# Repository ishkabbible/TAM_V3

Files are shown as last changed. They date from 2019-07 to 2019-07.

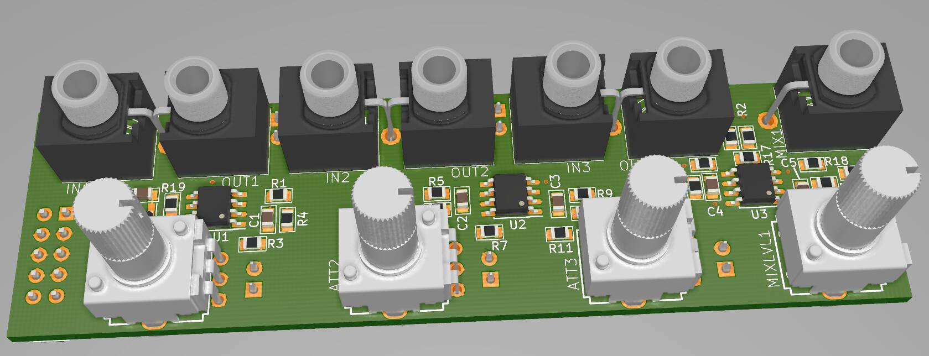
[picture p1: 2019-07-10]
active_3attMix_v3 PCB 3D front perspective.jpg

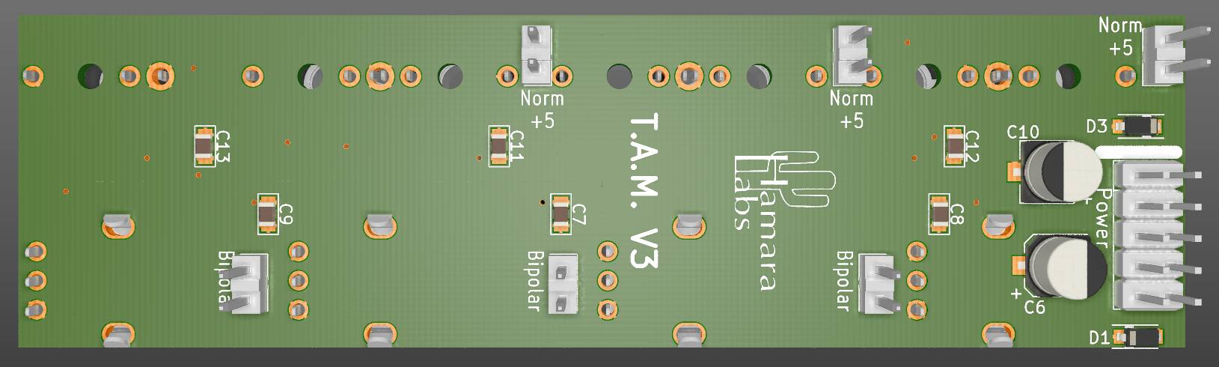
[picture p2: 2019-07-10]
active_3attMix_v3 PCB 3D back.jpg

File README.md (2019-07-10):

# Triple_Attenuverter_Mixer_v3

The TAM is three precision attenuators/attenuverters feeding into a 3-input, non-inverting mixer. The attenuXer sections are fully independent, and the output jacks are normalled to the mixer. Each section has 2 jumpers: one to select attenuator (gain = [0, +1]) or attenuverter (gain = [-1, +1]) operation. The other selects whether the input is normalled to +5V.

Additionally, this repository contains 2 different panel designs, the 3U x 6hp vertical panel, and a 1U x 20hp "tile" design. You will want to add knobs to the 1U build, since the pointer on the pots will be pointing sideways. The panel designs are identical to V2 and have not been updated.

LICENSE: The more I read about open source hardware licensing, the more confused I become. Apparently there is no real legal framework for it. That said, everyone seems to be doing it, so I'll join the crowd and hope the law eventually catches up with the people.
There is nothing unique or clever in this design, just the one op-amp attenuverter that everyone uses, and a non-inverting summer. I expect there are a dozen modules out there that have nearly the identical schematic. 
So I am releasing this design under the CC-BY-SA license. Feel free to contact me at ishkabbible at gmail.com if you feel I should be crediting you for any part of the design.

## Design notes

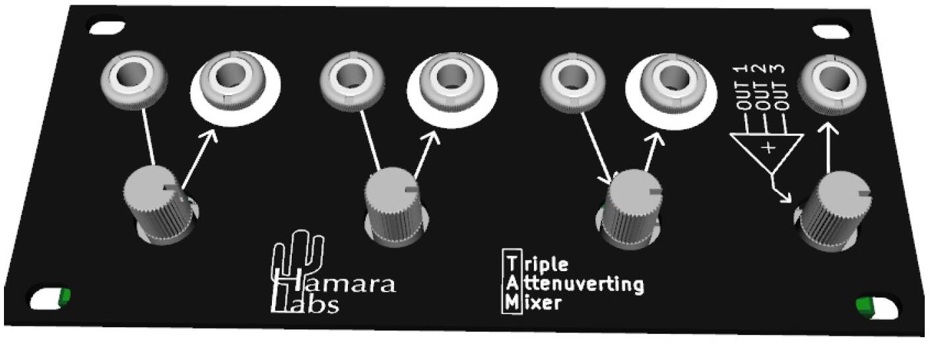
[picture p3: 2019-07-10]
active_3attMix V3 1u 3D.jpg

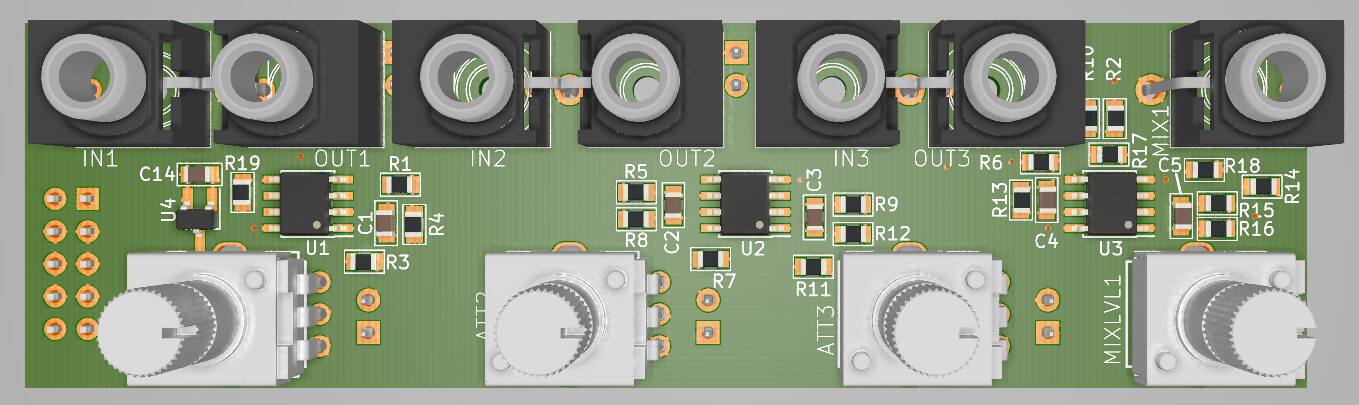
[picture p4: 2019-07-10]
active_3attMix_v3 PCB 3D front.jpg

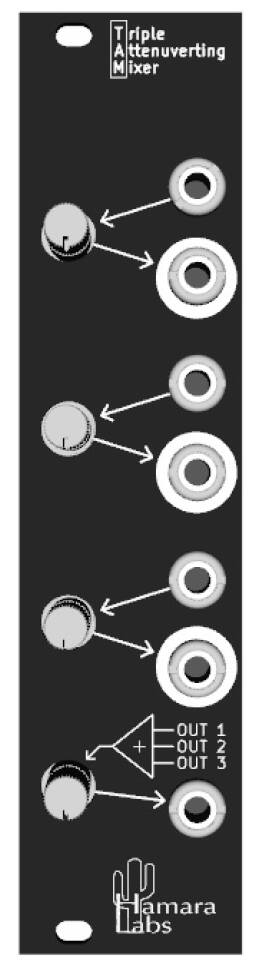
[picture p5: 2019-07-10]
active_3attMix_v3 3D front.jpg

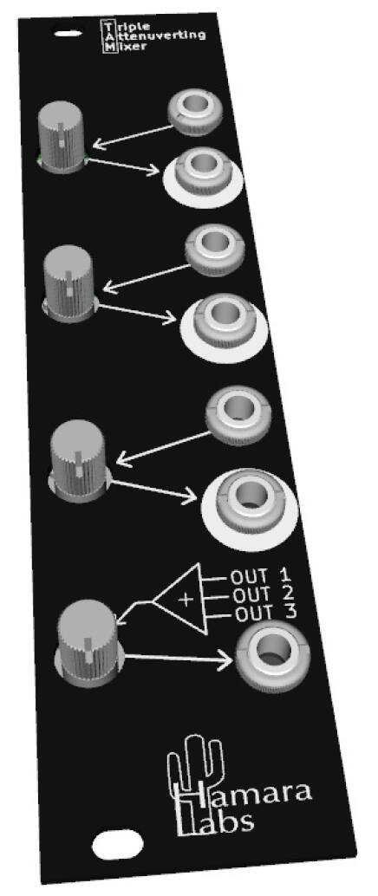
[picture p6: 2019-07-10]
active_3attMix_v3 3D front perspective.jpg

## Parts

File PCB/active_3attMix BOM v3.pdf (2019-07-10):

| | | | | NOTE: Prices are for rough planning only, they change on a daily basis
Quantity | Designator | Designation | Package | Vendor | | each | ext. | Notes
2 | C6,C10 | 22uF | CP_Elec_5x5.8 | Mouser | 667-EEE-FK1E220R (http://www.mouser.com/search/refine.aspx?Keyword=667-EEE-FK1E220R) | $0.41 | $0.82
1 | U4 | LM4040C50FTA | LM4040-5 | Mouser | 522-LM4040C50FTA (http://www.mouser.com/search/refine.aspx?Keyword=522-LM4040C50FTA) | $0.64 | $0.64 | Use LM4040A for more accurate 5V normaled to the inputs
3 | U1,U2,U3 | OPA1678IDR | SOIC-8_3.9x4.9mm_Pitch1.27mm | Mouser | 595-OPA1678IDR (https://www.mouser.com/Search/ProductDetail.aspx) | $0.83 | $2.49 | TL072 is cheaper if you don't care about performance
2 | D3,D1 | 1N5819HW-7-F | D_SOD-123 | Mouser | 621-1N5819HW-F (http://www.mouser.com/search/refine.aspx?Keyword=621-1N5819HW-F) | $0.44 | $0.88
1 | X1 | Header 2 x 5, 0.1" | HEADER_2.54_2x5 | | 538-10-89-7101 (http://www.mouser.com/ProductDetail/Molex/10-89-7101/) | $0.57 | $0.57 | Available cheaper elsewhere
6 | JP6,JP5,JP4,JP3,JP2,JP1 | header-2P, 0.1" | jump-2P | | 571-826936-2 (http://www.mouser.com/ProductDetail/TE-Connectivity/826936-2/) | $0.10 | $0.60 | Available cheaper elsewhere
7 | IN1,IN2,IN3,MIX1,OUT1,OUT2,OUT3 | PJ301M-12 / PJ398SM Jack | PJ301M-12_shared_ground | Thonk | https://www.thonk.co.uk/shop/3-5mm-jacks/ | $0.53 | $3.71 | must buy nuts separately. PJ398SM is upgraded part
3 | ATT1,ATT2,ATT3 | 100K | POT_SONG_HUEI_9mm_tall_trimmer | Thonk | https://www.thonk.co.uk/shop/ttpots/ | $1.11 | $3.33 | Linear for CV math, Audio for audio mixer
1 | MIXLVL1 | 10K | POT_SONG_HUEI_9mm_tall_trimmer | Thonk | https://www.thonk.co.uk/shop/ttpots/ | $1.11 | $1.11 | Linear for CV math, Audio for audio mixer
5 | C1,C2,C3,C4,C5 | 10pF | C_0805_DKH | Mouser | 77-VJ0805A100GXAPBC (https://www.mouser.com/Search/ProductDetail.aspx) | $0.10 | $0.50
7 | C7,C8,C9,C11,C12,C13,C14 | 100nF | C_0805_DKH | Mouser | 581-08055C104KAT4A (https://www.mouser.com/Search/ProductDetail.aspx) | $0.10 | $0.70
10 | R1,R2,R3,R5,R6,R7,R9,R10,R11,R15 | 200K, 0.1% | R_0805_DKH | Mouser | 603-AT0805BRD07200KL (https://www.mouser.com/Search/ProductDetail.aspx) | $0.26 | $2.61
4 | R4,R8,R12,R16 | 330R | R_0805_DKH | Mouser | 603-RC0805FR-07330RL (https://www.mouser.com/Search/ProductDetail.aspx) | $0.02 | $0.06 | buy 10
2 | R13,R14 | 120K, 0.1% | R_0805_DKH | Mouser | 603-RT0805BRD07120KL (https://www.mouser.com/Search/ProductDetail.aspx) | $0.39 | $0.78
1 | R17 | 43K | R_0805_DKH | Mouser | 603-RC0805FR-0743KL (https://www.mouser.com/Search/ProductDetail.aspx) | $0.10 | $0.10
1 | R18 | 75K | R_0805_DKH | Mouser | 603-RC0805FR-0775KL (https://www.mouser.com/Search/ProductDetail.aspx) | $0.10 | $0.10
1 | R19 | 10K | R_0805_DKH | Mouser | 603-RC0805FR-0710KL (https://www.mouser.com/Search/ProductDetail.aspx) | $0.10 | $0.10
6 | JP6,JP5,JP4,JP3,JP2,JP1 | | 2-pin Jumpers | Mouser | 806-SX1100-B (http://www.mouser.com/ProductDetail/Kycon/SX1100-B/) | $0.02 | $0.13 | buy 25, available cheaper elsewhere

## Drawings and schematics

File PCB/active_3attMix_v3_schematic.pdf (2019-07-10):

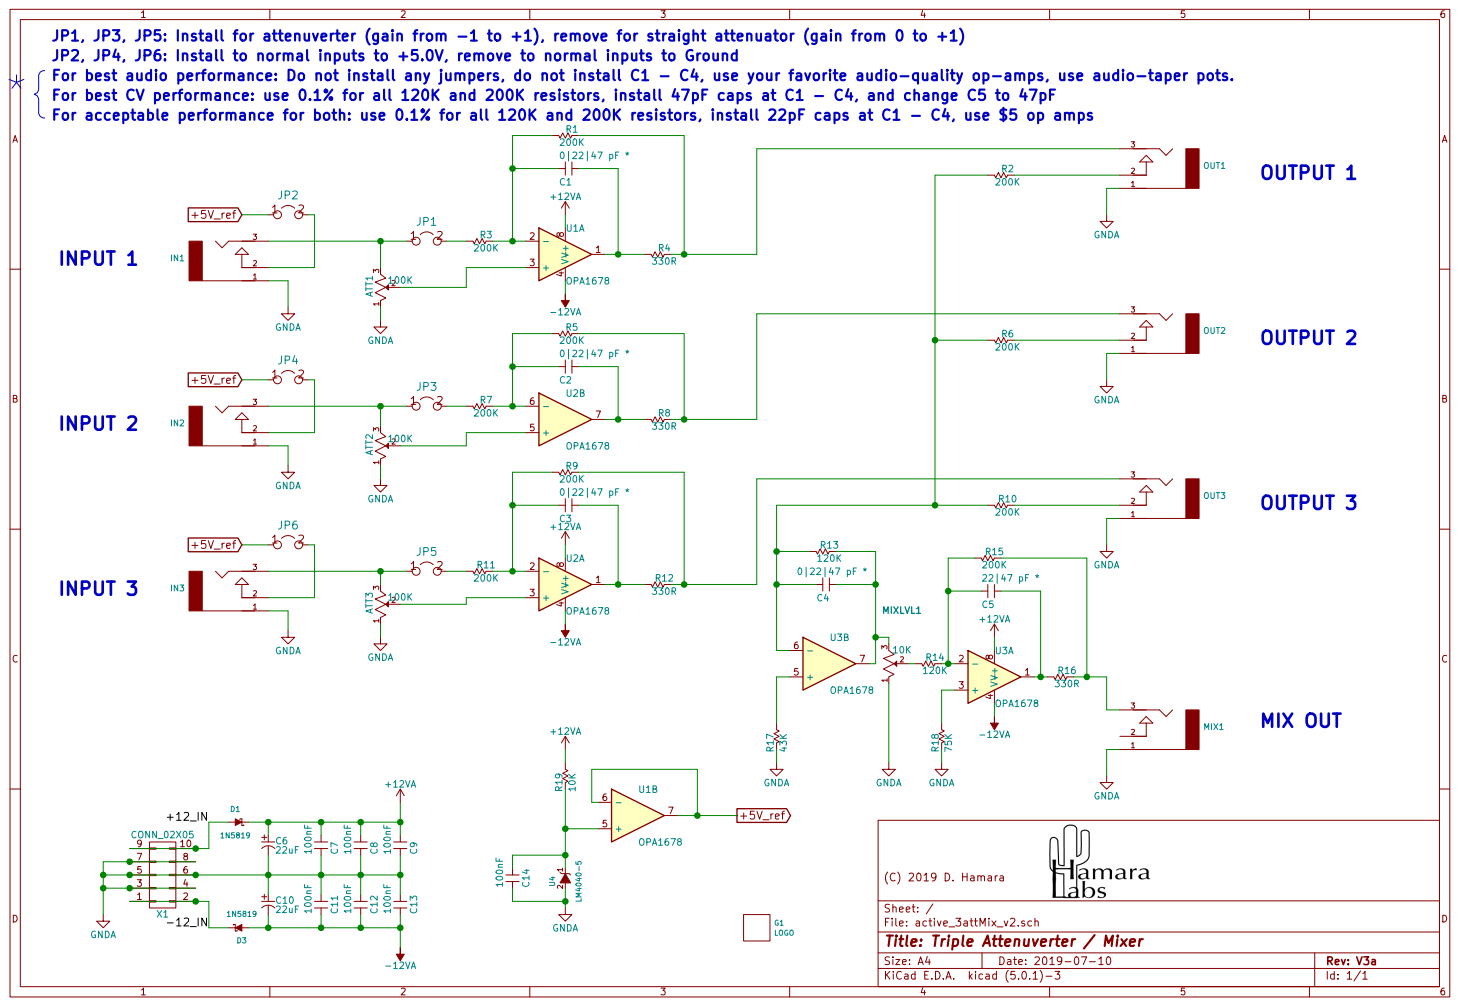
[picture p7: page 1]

JP1, JP3, JP5: Install for attenuverter (gain from -1 to +1), remove for straight attenuator (gain from 0 to +1)
JP2, JP4, JP6: Install to normal inputs to +5.0V, remove to normal inputs to Ground
For acceptable performance for both: use 0.1% for all 120K and 200K resistors, install 22pF caps at C1 - C4, use $5 op amps *{
120K For best audio performance: Do not install any jumpers, do not install C1 - C4, use your favorite audio-quality op-amps, use audio-taper pots.
For best CV performance: use 0.1% for all 120K and 200K resistors, install 47pF caps at C1 - C4, and change C5 to 47pF

File: active_3attMix_v2.sch Sheet: / (C) 2019 D. Hamara

Id: 1/1 Title: Triple Attenuverter / Mixer

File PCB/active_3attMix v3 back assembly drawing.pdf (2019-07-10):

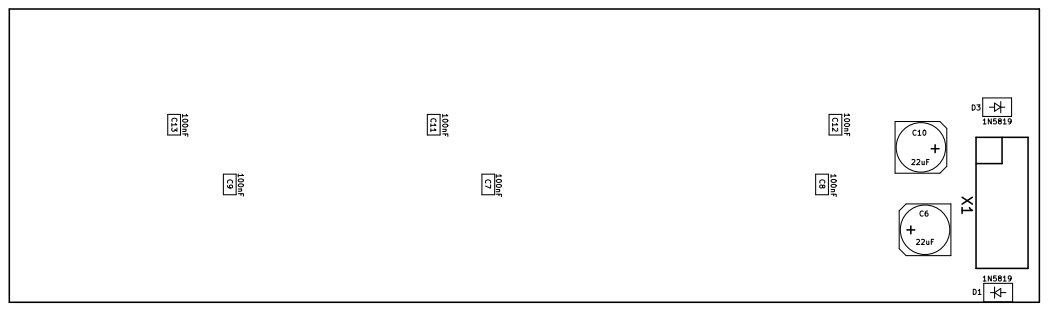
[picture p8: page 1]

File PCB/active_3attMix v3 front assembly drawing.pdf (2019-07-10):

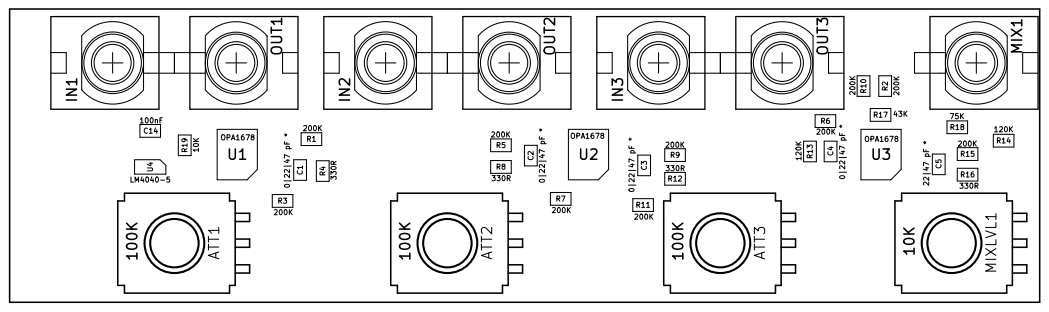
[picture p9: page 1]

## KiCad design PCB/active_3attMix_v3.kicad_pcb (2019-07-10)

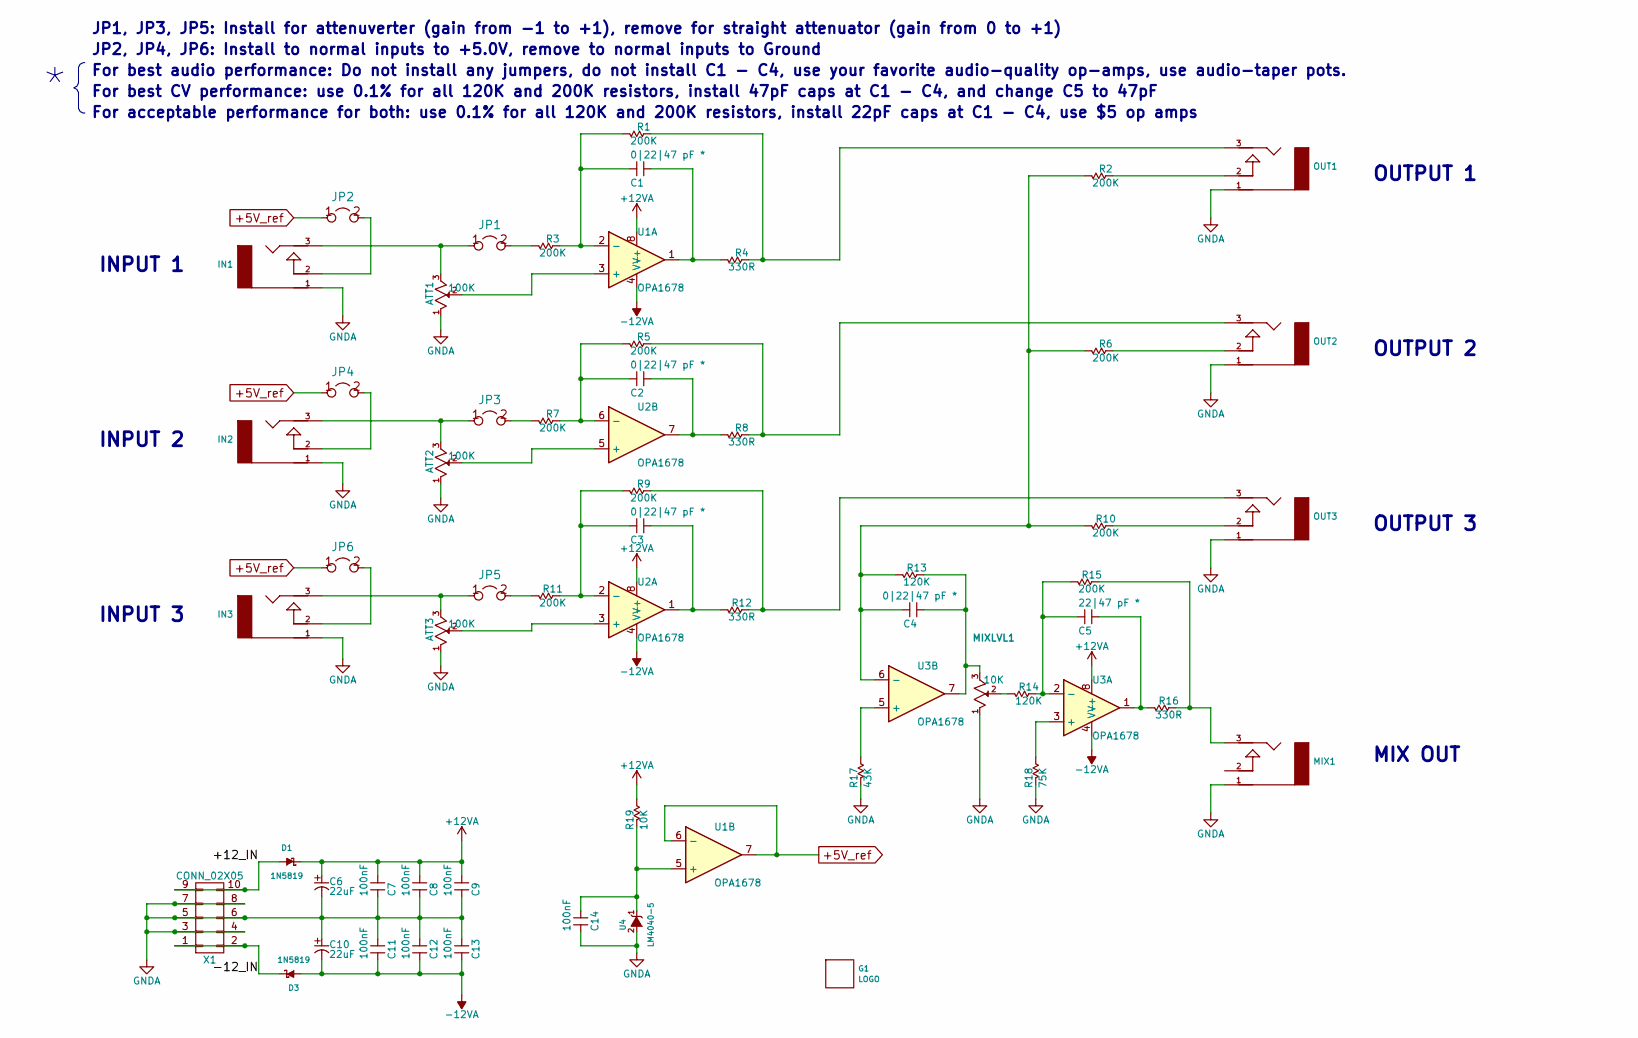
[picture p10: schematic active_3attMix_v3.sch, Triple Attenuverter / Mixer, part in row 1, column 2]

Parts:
ATT1, ATT2, ATT3: 100K; POT_SONG_HUEI_9mm_tall_trimmer
C1, C2, C3, C4: 0|22|47 pF *; C_0805_DKH
C5: 22|47 pF *; C_0805_DKH
C6, C10: 22uF; CP_Elec_5x5.8
C7, C8, C9, C11, C12, C13, C14: 100nF; C_0805_DKH
D1, D3: 1N5819; D_SOD-123
G1: LOGO; Hamara_labs_4_tiny
IN1, IN2, IN3: AUDIO-JACK-PJ301M-12; PJ301M-12_veils_sharedGround
JP1, JP2, JP3, JP4, JP5, JP6: header-2P; jump-2P
MIX1: AUDIO-JACK-PJ301M-12; PJ301M-12_veils_sharedGround
MIXLVL1: 10K; POT_SONG_HUEI_9mm_tall_trimmer
OUT1, OUT2, OUT3: AUDIO-JACK-PJ301M-12; PJ301M-12_veils_sharedGround
R1, R2, R3, R5, R6, R7, R9, R10, R11, R15: 200K; R_0805_DKH_hand
R4, R8, R12, R16: 330R; R_0805_DKH_hand
R13, R14: 120K; R_0805_DKH_hand
R17: 43K; R_0805_DKH_hand
R18: 75K; R_0805_DKH_hand
R19: 10K; R_0805_DKH_hand
U1, U2, U3: OPA1678; SOIC-8_3.9x4.9mm_Pitch1.27mm
U4: LM4040-5; SOT-23_Handsoldering
X1: CONN_02X05; HEADER_2.54_2x5

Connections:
+5V_ref: JP2.1, JP4.1, JP6.1, U1.6 (-), U1.7
+12VA: C6.1, C7.1, C8.1, C9.1, D1.1 (K), R19.2, U1.8 (V+), U2.8 (V+), U3.8 (V+)
-12VA: C10.2, C11.2, C12.2, C13.2, D3.2 (A), U1.4 (V-), U2.4 (V-), U3.4 (V-)
/+12_IN: D1.2 (A), X1.9, X1.10
/-12_IN: D3.1 (K), X1.1, X1.2
GNDA: ATT1.1, ATT2.1, ATT3.1, C6.2, C7.2, C8.2, C9.2, C10.1, C11.1, C12.1, C13.1, C14.2, IN1.1 (RING), IN2.1 (RING), IN3.1 (RING), MIX1.1 (RING), MIXLVL1.1, OUT1.1 (RING), OUT2.1 (RING), OUT3.1 (RING), R17.1, R18.1, U4.2 (A), X1.3, X1.4, X1.5, X1.6, X1.7, X1.8
unnamed: ATT1.2, U1.3 (+)
unnamed: ATT1.3, IN1.3 (TIP), JP1.1
unnamed: ATT2.2, U2.5 (+)
unnamed: ATT2.3, IN2.3 (TIP), JP3.1
unnamed: ATT3.2, U2.3 (+)
unnamed: ATT3.3, IN3.3 (TIP), JP5.1
unnamed: C1.1, R4.2, U1.1
unnamed: C1.2, R1.2, R3.1, U1.2 (-)
unnamed: C2.1, R8.2, U2.7
unnamed: C2.2, R5.2, R7.1, U2.6 (-)
unnamed: C3.1, R12.2, U2.1
unnamed: C3.2, R9.2, R11.1, U2.2 (-)
unnamed: C4.1, MIXLVL1.3, R13.1, U3.7
unnamed: C4.2, R2.2, R6.2, R10.2, R13.2, U3.6 (-)
unnamed: C5.1, R16.2, U3.1
unnamed: C5.2, R14.1, R15.2, U3.2 (-)
unnamed: C14.1, R19.1, U1.5 (+), U4.1 (K)
unnamed: IN1.2 (NORM), JP2.2
unnamed: IN2.2 (NORM), JP4.2
unnamed: IN3.2 (NORM), JP6.2
unnamed: JP1.2, R3.2
unnamed: JP3.2, R7.2
unnamed: JP5.2, R11.2
unnamed: MIX1.3 (TIP), R15.1, R16.1
unnamed: MIXLVL1.2, R14.2
unnamed: OUT1.2 (NORM), R2.1
unnamed: OUT1.3 (TIP), R1.1, R4.1
unnamed: OUT2.2 (NORM), R6.1
unnamed: OUT2.3 (TIP), R5.1, R8.1
unnamed: OUT3.2 (NORM), R10.1
unnamed: OUT3.3 (TIP), R9.1, R12.1
unnamed: R17.2, U3.5 (+)
unnamed: R18.2, U3.3 (+)

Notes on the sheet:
INPUT 1
INPUT 2
INPUT 3
OUTPUT 1
OUTPUT 2
OUTPUT 3
MIX OUT
JP1, JP3, JP5: Install for attenuverter (gain from -1 to +1), remove for straight attenuator (gain from 0 to +1)
JP2, JP4, JP6: Install to normal inputs to +5.0V, remove to normal inputs to Ground
For best audio performance: Do not install any jumpers, do not install C1 - C4, use your favorite audio-quality op-amps, use audio-taper pots.
For best CV performance: use 0.1% for all 120K and 200K resistors, install 47pF caps at C1 - C4, and change C5 to 47pF
For acceptable performance for both: use 0.1% for all 120K and 200K resistors, install 22pF caps at C1 - C4, use $5 op amps

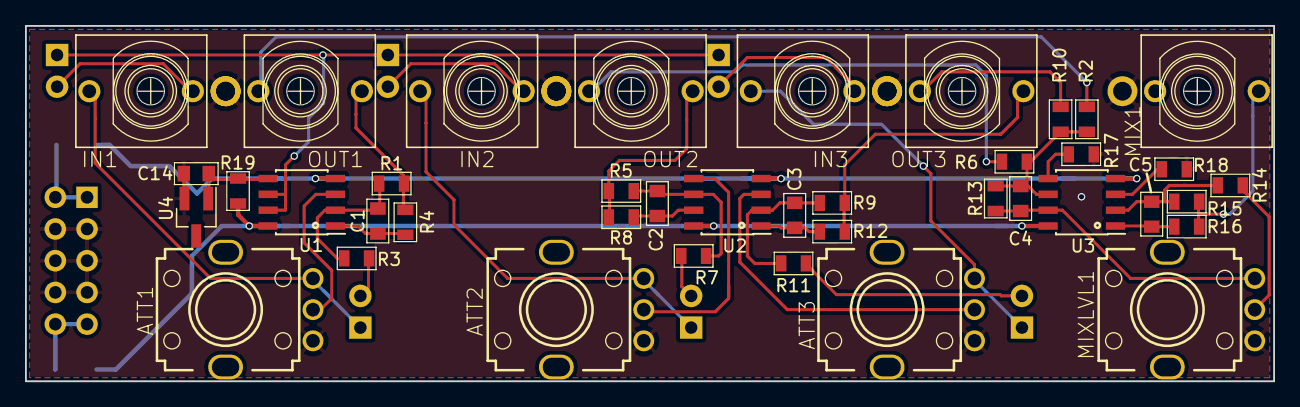
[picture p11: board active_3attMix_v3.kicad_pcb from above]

Board: 2 copper layers, 100.0 x 28.5 mm, 58 parts (0 on the bottom side), 39 nets.
